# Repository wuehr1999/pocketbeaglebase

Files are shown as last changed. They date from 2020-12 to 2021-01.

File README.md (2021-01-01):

# pocketbeaglebase

Add lots of useful features to Your PocketBeagle.

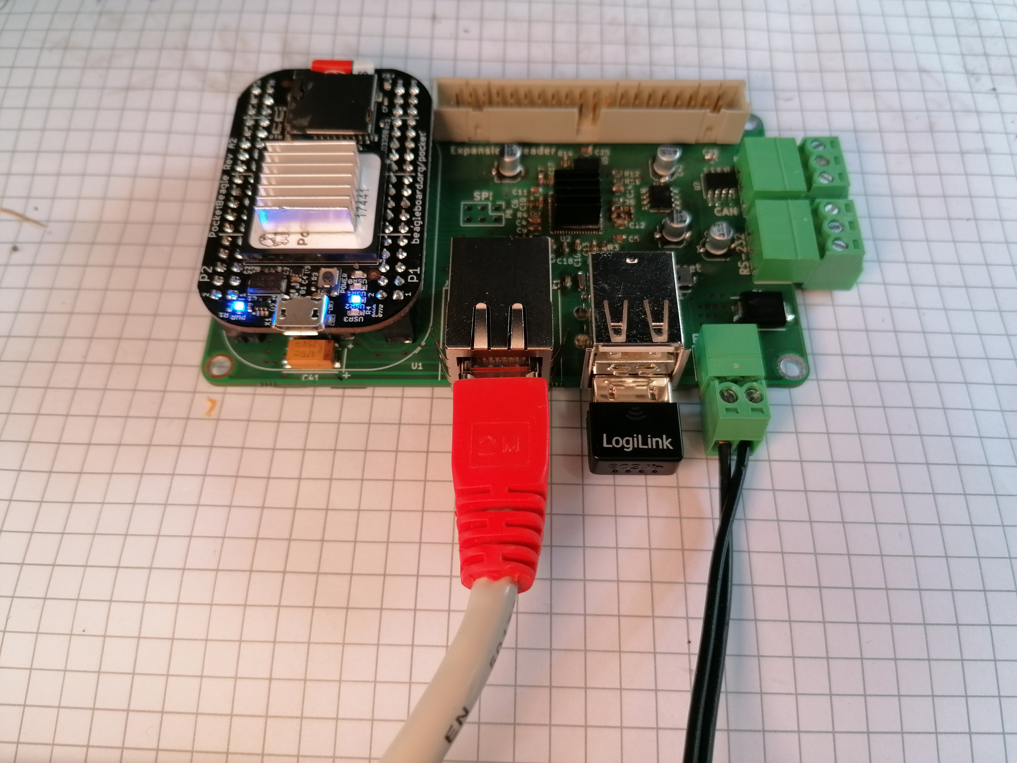
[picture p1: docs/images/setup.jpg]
pocketbeaglebase in use


## Features

* Input voltage range: 5 - 28V
* 10/100 Base-T/TX ethernet interface
* 2 USB 2.0 connectors
* RS-232 interface
* CAN interface
* Qwiic connectors: 2 x UART, PRU1 UART, ISC1
* SPI header
* GPIO header

## Connectors

### SPI1 header (P8)

| Pin | Function |
|-----|---|
| 1 | MISO |
| 2 | 3V3 |
| 3 | SCK |
| 4 | MOSI |
| 5 | CS |
| 6 | GND |

### GPIO header (P4)

| Pin | Function |
|-----|---|
| 1 | AIN7 |
| 2 | AIN5 |
| 3 | PRU0.5 |
| 4 | IO45 |
| 5 | PRU0.3 |
| 6 | PRU0.2 |
| 7 | IO48 |
| 8 | PRU0.6 |
| 9 | IO64 |
| 10 | IO46 |
| 11 | IO65 |
| 12 | IO27 |
| 13 | IO52 |
| 14 | IO47 |
| 15 | IO60 |
| 16 | IO57 |
| 17 | IO58 |
| 18 | IO23 |
| 19 | IO59 |
| 20 | PWM0A |
| 21 | PWM0B |
| 22 | 3V3 |
| 23 | PRU1.10 |
| 24 | IO26 |
| 25 | PRU0.1 |
| 26 | PRU0.4 |
| 27 | PRU0.7 |
| 28 | AIN4 |
| 29 | NC |
| 30 | AIN3 |
| 31 | NC |
| 32 | AIN2 |
| 33 | AIN1 |
| 34 | IO20 |
| 35 | AIN0 | 
| 36 | VRef+ |
| 37 | VRef- |
| 38 | IO89 |
| 39 | AIN6 |
| 40 | GND |

### RS-232 (UART 0)

| Pin | Function |
|-----|---|
| 1 | TX |
| 2 | RX |
| 3 | GND |

### CAN (CAN 0)

| Pin | Function |
|-----|---|
| 1 | CANH |
| 2 | CANL |
| 3 | GND |

The termination can be enabled by closing solder jumper P9 on the bottom of the board.

### UART2, UART4, UARTPRU1 over Qwiic (P3, P5, P6)

| Pin | Function |
|-----|---|
| 1 | GND |
| 2 | 3v3 |
| 3 | TX |
| 4 | RX |

### I2C1 over Qwiic (P7)

| Pin | Function |
|-----|---|
| 1 | GND |
| 2 | 3v3 |
| 3 | SDA |
| 4 | SCL |

## PCB

### Toplayer

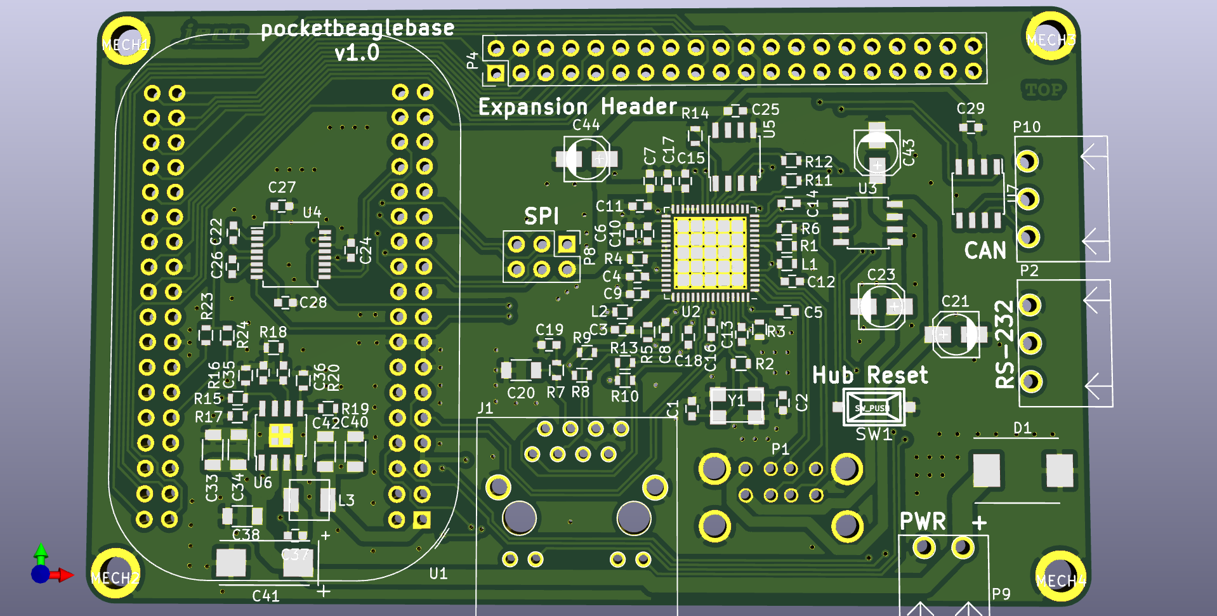
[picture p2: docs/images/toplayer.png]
toplayer


### Bottomlayer

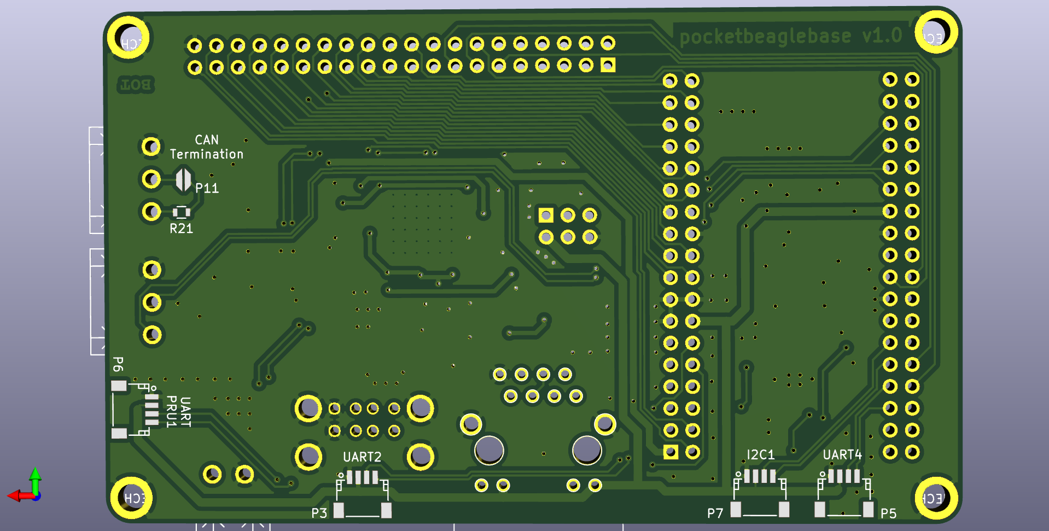
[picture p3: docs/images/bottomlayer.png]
bottomlayer


## Resources

### Manuals

* PocketBeagle System Reference Manual: https://github.com/beagleboard/pocketbeagle/wiki/System-Reference-Manual
* BeagleBone PRU Cookbook: http://beagleboard.org/static/prucookbook/

### Datasheets

* http://ww1.microchip.com/downloads/en/devicedoc/00002306a.pdf
* https://octavosystems.com/docs/osd335x-sm-datasheet/
* https://www.ti.com/lit/ds/symlink/sn65hvd230.pdf?HQS=dis-dk-null-digikeymode-dsf-pf-null-wwe&ts=1609524456800
* https://datasheets.maximintegrated.com/en/ds/MAX3224-MAX3245.pdf
* https://www.ti.com/lit/ds/symlink/tps54335-2a.pdf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
* http://ww1.microchip.com/downloads/en/devicedoc/21712b.pdf
* https://cdn-reichelt.de/documents/datenblatt/C100/M100_T1D_33E4G_DB_DE.pdf

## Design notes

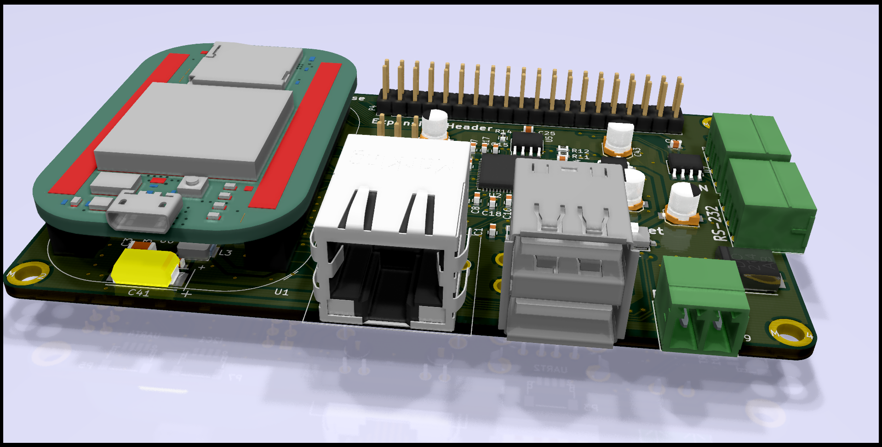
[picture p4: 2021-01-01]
docs/images/rendering.png

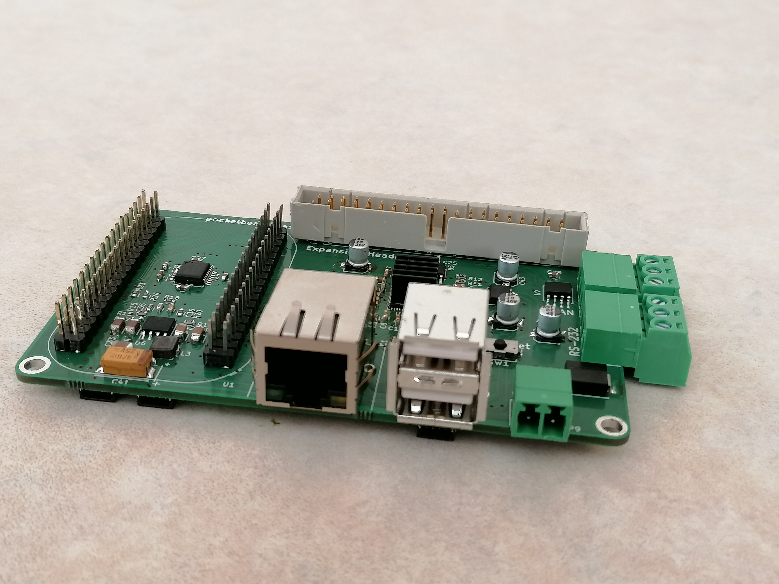
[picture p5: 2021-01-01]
docs/images/topside.jpg

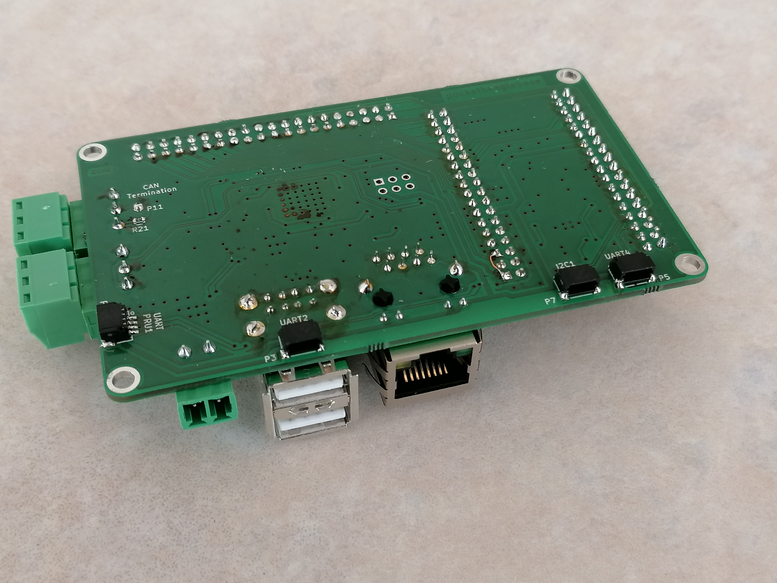
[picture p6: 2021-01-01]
docs/images/bottomside.jpg

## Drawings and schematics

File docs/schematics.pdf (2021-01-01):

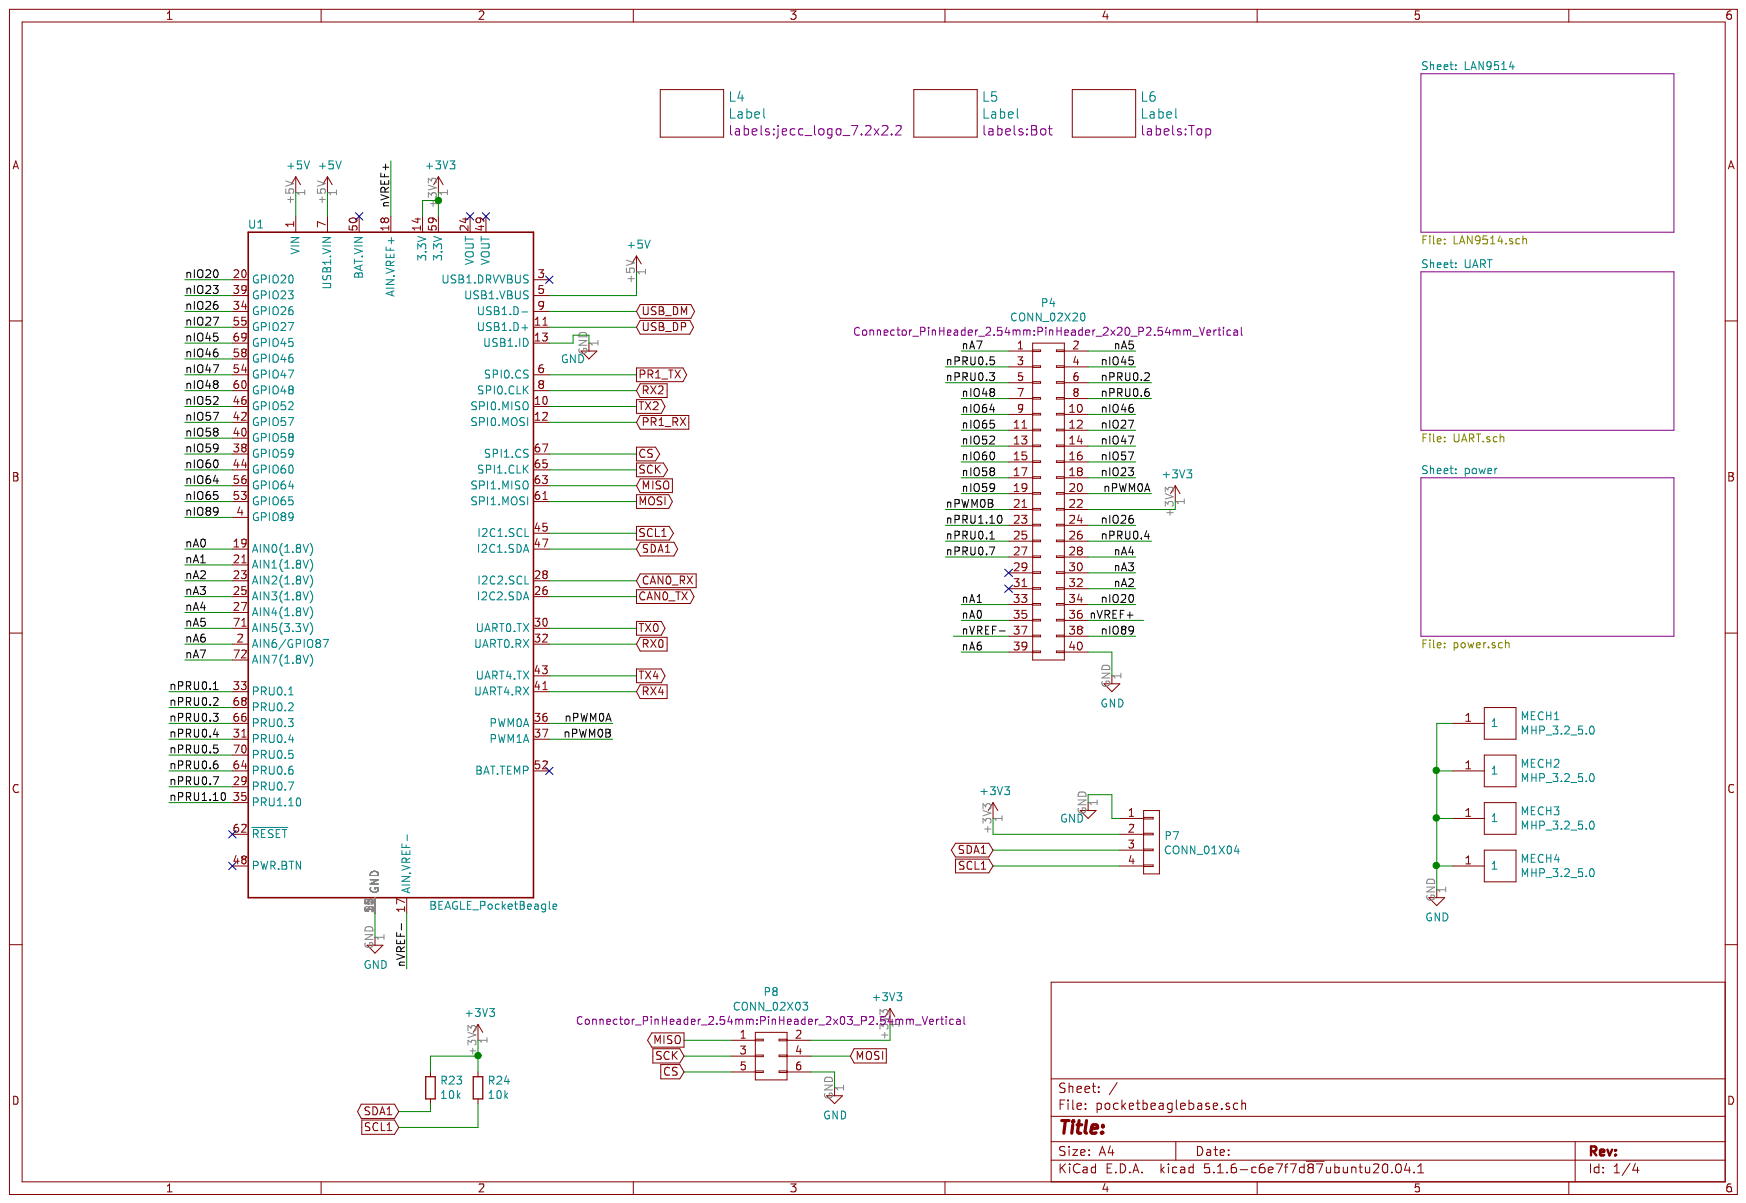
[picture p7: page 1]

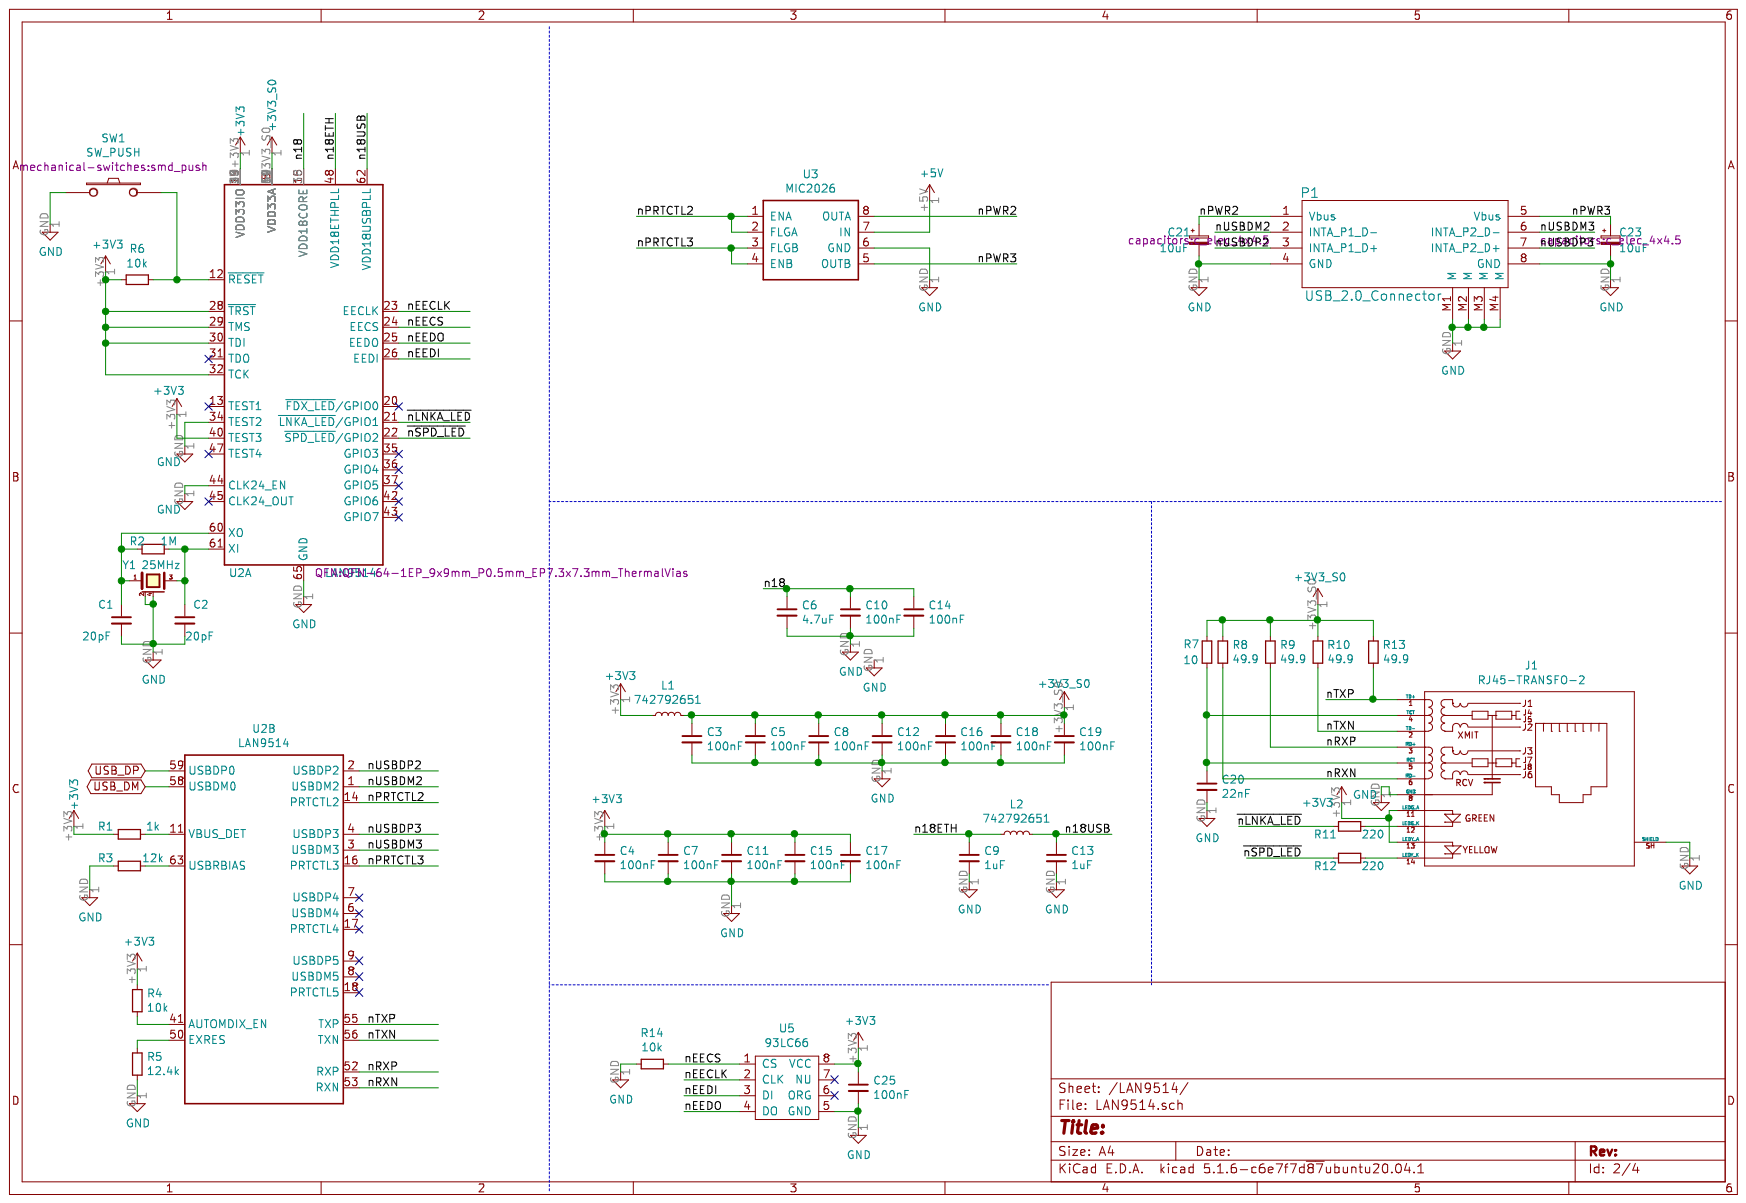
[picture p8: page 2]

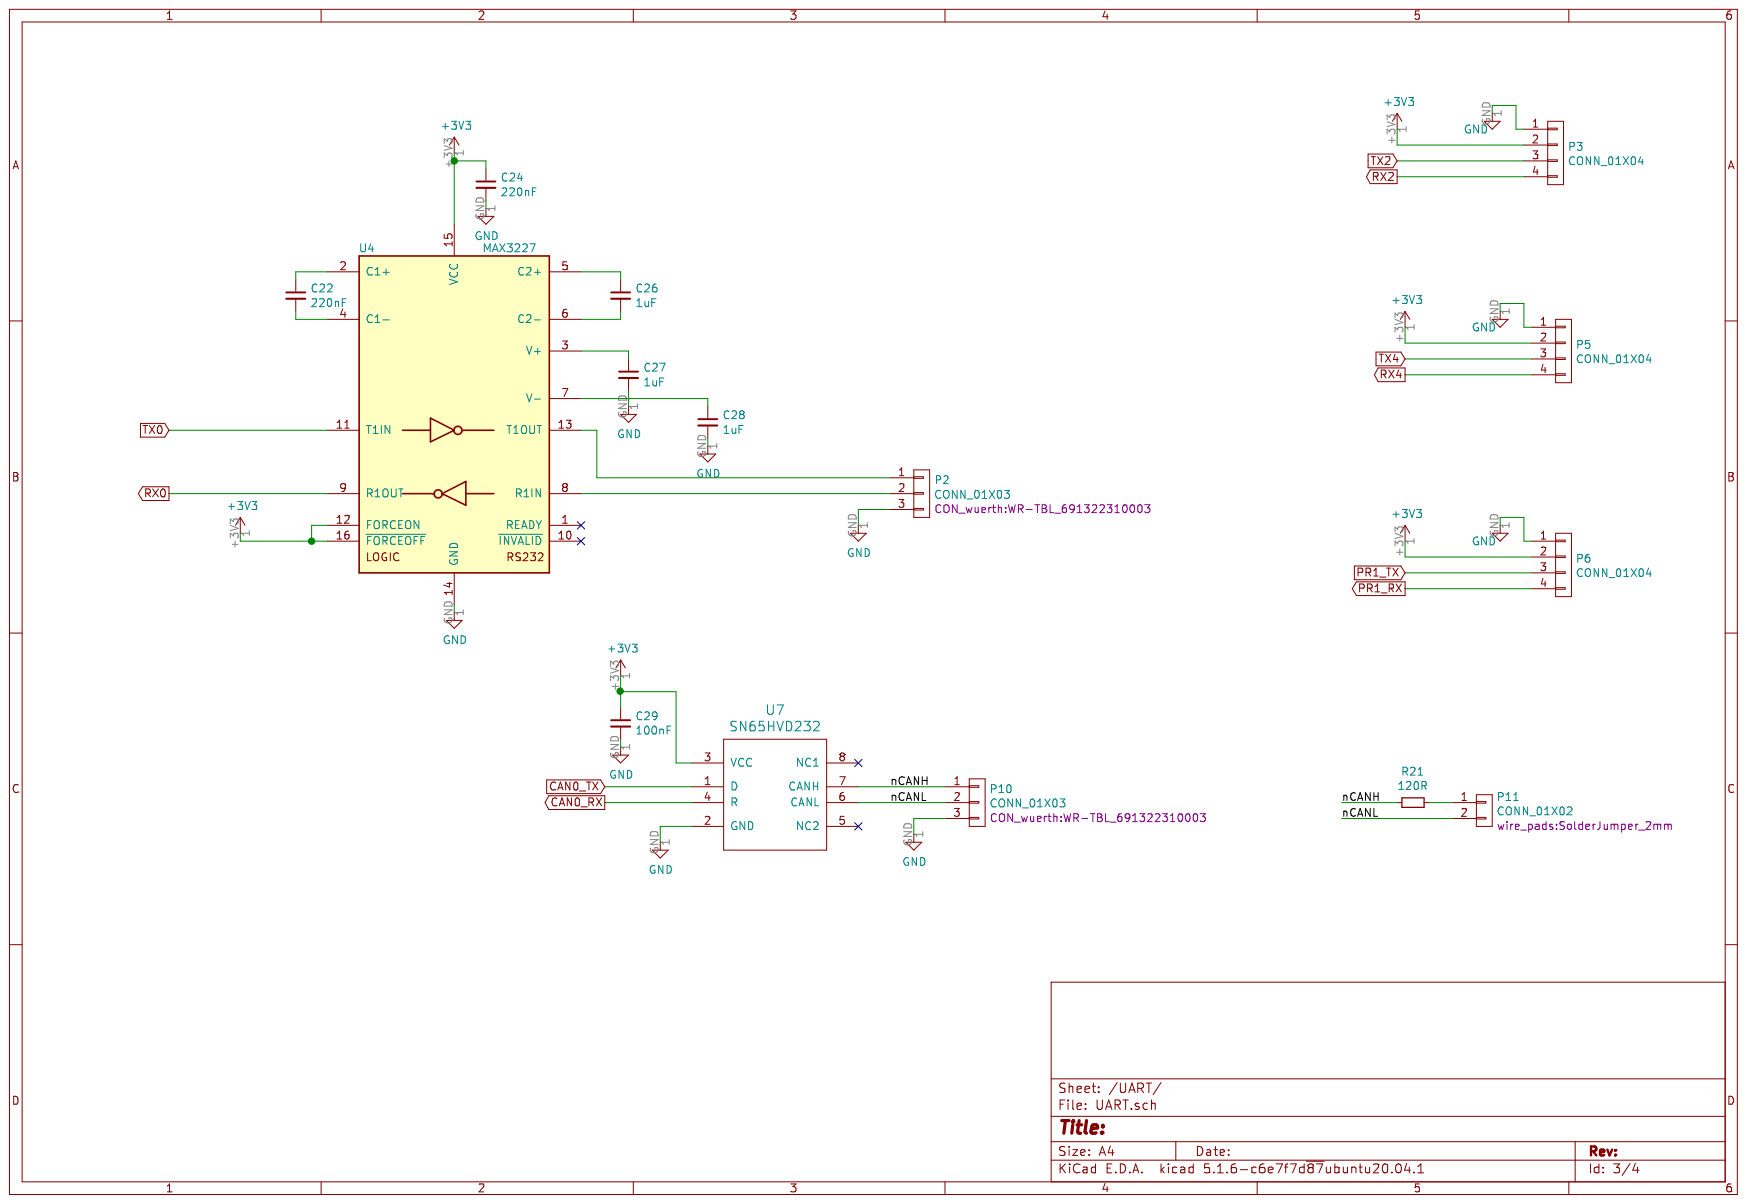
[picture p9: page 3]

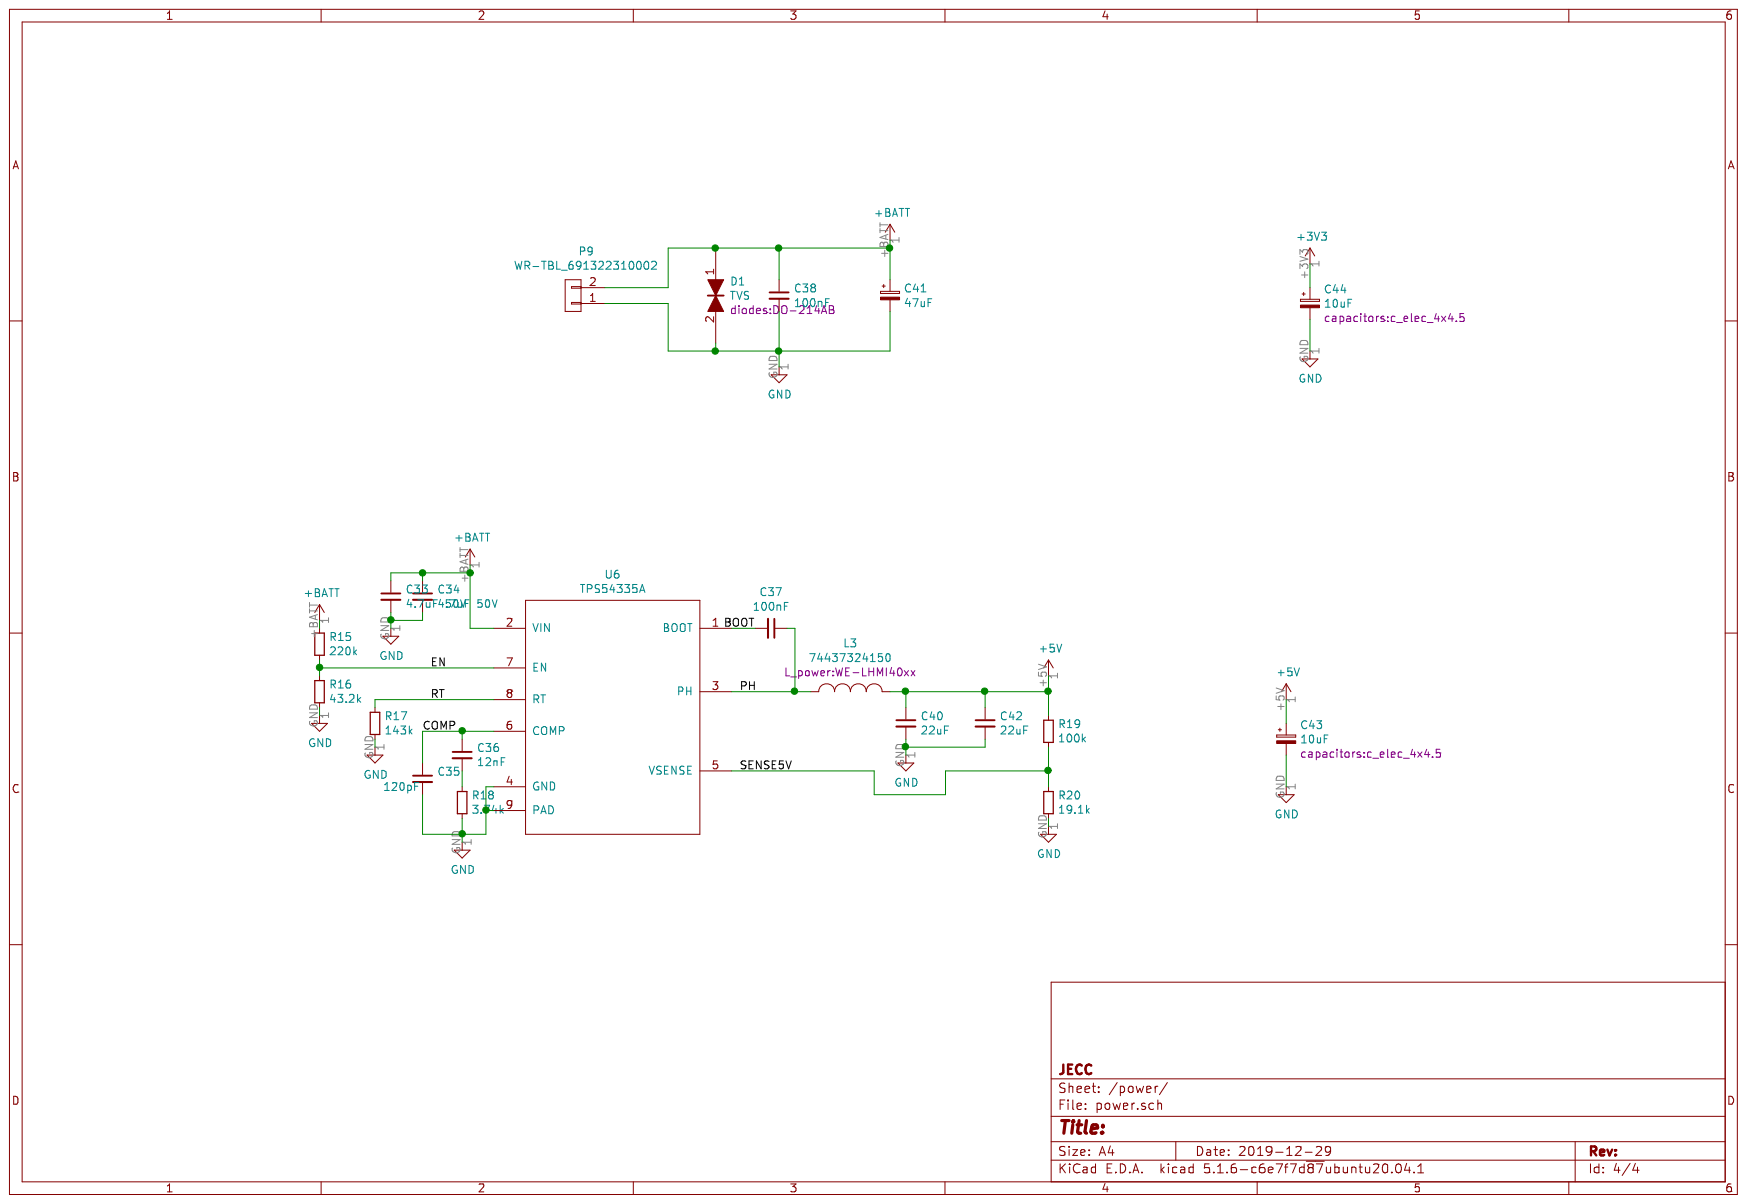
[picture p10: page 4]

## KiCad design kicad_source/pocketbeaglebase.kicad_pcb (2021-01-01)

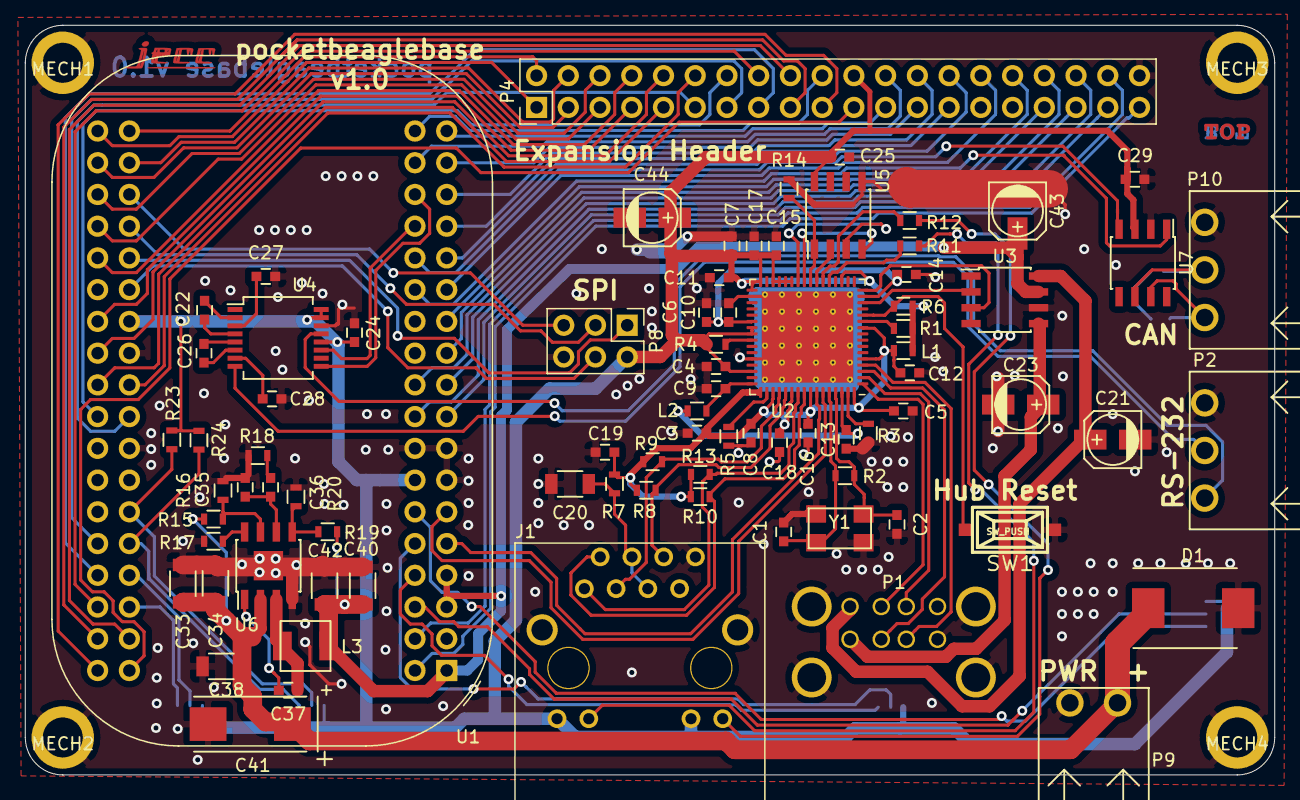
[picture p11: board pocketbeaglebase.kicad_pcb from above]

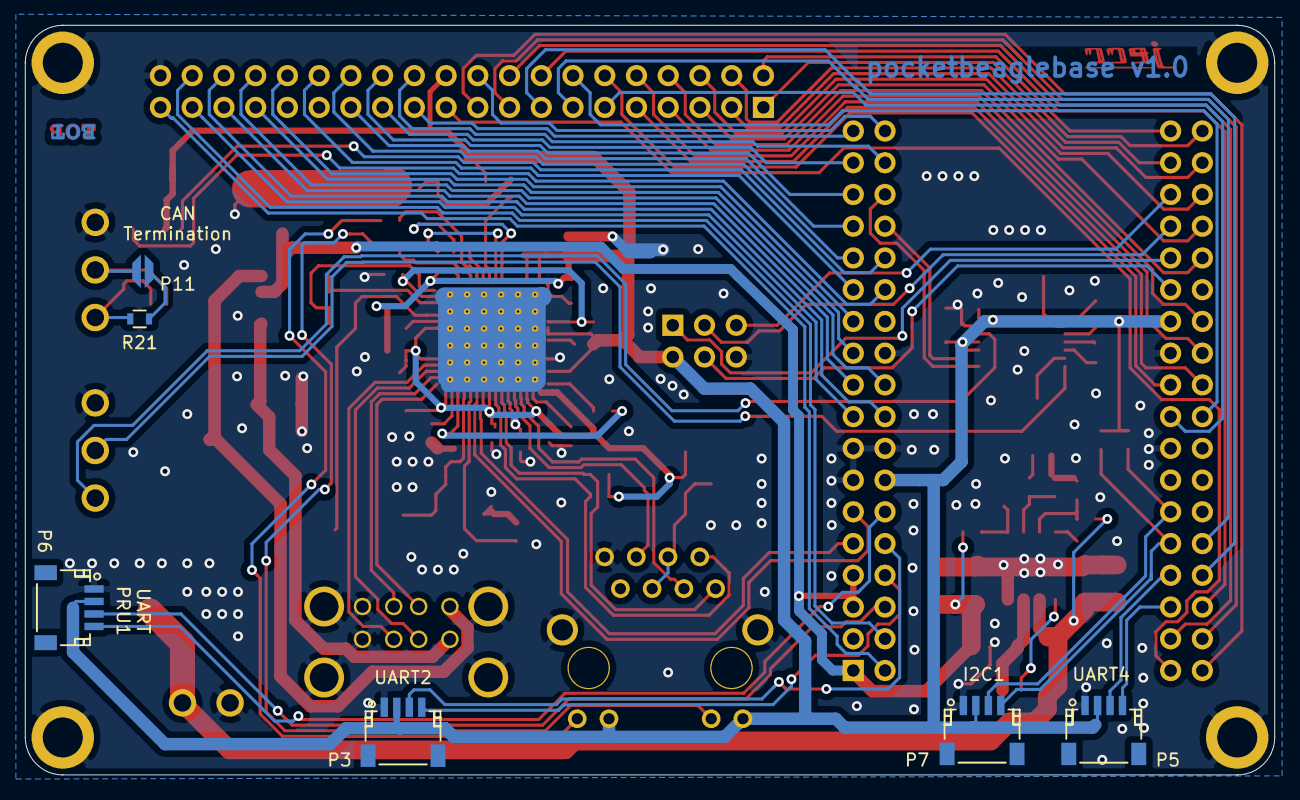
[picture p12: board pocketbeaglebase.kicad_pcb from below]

Board: 2 copper layers, 100.0 x 60.0 mm, 95 parts (6 on the bottom side), 108 nets.

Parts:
C1, C2: 330pF; C_0603
C3, C4, C5, C7, C8, C10, C11, C12, C14, C15, C16, C17, C18, C19, C25, C29, C37: 100nF; C_0603
C6: 4.7uF; C_0603
C9, C13, C26, C27, C28: 1uF; C_0603
C20: 22nF; C_1206
C21, C23, C43, C44: 10uF; c_elec_4x4.5
C22, C24: 220nF; C_0603
C33, C34: 4.7uF 50V; C_1206
C35: 120pF; C_0603
C36: 12nF; C_0603
C38: 100nF; C_1206
C40, C42: 22uF; C_1206
C41: 47uF; TantalC_SizeD_EIA-7343_Wave
D1: TVS; DO-214AB
J1: RJ45-TRANSFO-2; RJ_45_TRANSFO_2
L1, L2: 742792651; R_0603
L3: 74437324150; WE-LHMI40xx
L4: Label; jecc_logo_7.2x2.2
L5: Label; Bot
L6: Label; Top
MECH1, MECH2, MECH3, MECH4: MHP_3.2_5.0
P1: USB_2.0_Connector; WE-61400826021
P2, P10: CONN_01X03; WR-TBL_691322310003
P3, P5, P6, P7: CONN_01X04; Connectors_JST_SM04B-SRSS-TB
P4: CONN_02X20; PinHeader_2x20_P2.54mm_Vertical
P8: CONN_02X03; PinHeader_2x03_P2.54mm_Vertical
P9: WR-TBL_691322310002
P11: CONN_01X02; SolderJumper_2mm
R1: 1k; R_0603
R2: 1M; R_0603
R3: 12k; R_0603
R4, R6, R14, R23, R24: 10k; R_0603
R5: 12.4k; R_0603
R7: 10; R_0603
R8, R9, R10, R13: 49.9; R_0603
R11, R12: 220; R_0603
R15: 220k; R_0603
R16: 43.2k; R_0603
R17: 143k; R_0603
R18: 3.74k; R_0603
R19: 100k; R_0603
R20: 19.1k; R_0603
R21: 120R; R_0603
SW1: SW_PUSH; smd_push
U1: BEAGLE_PocketBeagle
U2: LAN9514; QFN-64-1EP_9x9mm_P0.5mm_EP7.3x7.3mm_ThermalVias
U3: MIC2026; SOIC-8_3.9x4.9mm_Pitch1.27mm
U4: MAX3227; SSOP-16_5.3x6.2mm_Pitch0.65mm
U5: 93LC66; SOIC-8_3.9x4.9mm_Pitch1.27mm
U6: TPS54335A; SOIC-8-1EP_3.9x4.9mm_Pitch1.27mm
U7: SN65HVD232; SOIC-8_3.9x4.9mm_Pitch1.27mm
Y1: 25MHz; Crystal_SMD_5x3.2mm_4Pad

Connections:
+3V3: C4.1, C7.1, C11.1, C15.1, C17.1, C24.1, C25.1, C29.1, C44.1, J1.11, J1.13, L1.1, P3.2, P4.22, P5.2, P6.2, P7.2, P8.2, R1.2, R4.1, R6.2, R23.1, R24.1, U1.14, U1.59, U2.19, U2.27, U2.28, U2.29, U2.30, U2.32, U2.33, U2.39, U2.40, U2.46, U4.12, U4.15, U4.16, U5.8, U7.3
+3V3_S0: C3.1, C5.1, C8.1, C12.1, C16.1, C18.1, C19.1, L1.2, R7.1, R8.1, R9.1, R10.1, R13.1, U2.5, U2.10, U2.49, U2.51, U2.54, U2.57, U2.64
+5V: C40.1, C42.1, C43.1, L3.2, R19.1, U1.1, U1.5, U1.7, U3.7
+BATT: C33.1, C34.1, C38.1, C41.1, D1.1, P9.2, R15.1, U6.2
/LAN9514/n18: C6.1, C10.1, C14.1, U2.15, U2.38
/LAN9514/n18ETH: C9.1, L2.1, U2.48
/LAN9514/n18USB: C13.1, L2.2, U2.62
/LAN9514/nEECLK: U2.23, U5.2
/LAN9514/nEECS: R14.1, U2.24, U5.1
/LAN9514/nEEDI: U2.26, U5.3
/LAN9514/nEEDO: U2.25, U5.4
/LAN9514/nPRTCTL2: U2.14, U3.1, U3.2
/LAN9514/nPRTCTL3: U2.16, U3.3, U3.4
/LAN9514/nPWR2: C21.1, P1.1, U3.8
/LAN9514/nPWR3: C23.1, P1.5, U3.5
/LAN9514/nRXN: J1.6, R8.2, U2.53
/LAN9514/nRXP: J1.3, R9.2, U2.52
/LAN9514/nTXN: J1.2, R10.2, U2.56
/LAN9514/nTXP: J1.1, R13.2, U2.55
/LAN9514/nUSBDM2: P1.2, U2.1
/LAN9514/nUSBDM3: P1.6, U2.3
/LAN9514/nUSBDP2: P1.3, U2.2
/LAN9514/nUSBDP3: P1.7, U2.4
/LAN9514/~nLNKA_LED: R11.1, U2.21
/LAN9514/~nSPD_LED: R12.1, U2.22
/UART/nCANH: P10.1, R21.2, U7.7
/UART/nCANL: P10.2, P11.2, U7.6
/nA0: P4.35, U1.19
/nA1: P4.33, U1.21
/nA2: P4.32, U1.23
/nA3: P4.30, U1.25
/nA4: P4.28, U1.27
/nA5: P4.2, U1.71
/nA6: P4.39, U1.2
/nA7: P4.1, U1.72
/nIO20: P4.34, U1.20
/nIO23: P4.18, U1.39
/nIO26: P4.24, U1.34
/nIO27: P4.12, U1.55
/nIO45: P4.4, U1.69
/nIO46: P4.10, U1.58
/nIO47: P4.14, U1.54
/nIO48: P4.7, U1.60
/nIO52: P4.13, U1.46
/nIO57: P4.16, U1.42
/nIO58: P4.17, U1.40
/nIO59: P4.19, U1.38
/nIO60: P4.15, U1.44
/nIO64: P4.9, U1.56
/nIO65: P4.11, U1.53
/nIO89: P4.38, U1.4
/nPRU0.1: P4.25, U1.33
/nPRU0.2: P4.6, U1.68
/nPRU0.3: P4.5, U1.66
/nPRU0.4: P4.26, U1.31
/nPRU0.5: P4.3, U1.70
/nPRU0.6: P4.8, U1.64
/nPRU0.7: P4.27, U1.29
/nPRU1.10: P4.23, U1.35
/nPWM0A: P4.20, U1.36
/nPWM0B: P4.21, U1.37
/nVREF+: P4.36, U1.18
/nVREF-: P4.37, U1.17
/power/COMP: C35.1, C36.1, U6.6
/power/EN: R15.2, R16.1, U6.7
/power/PH: C37.1, L3.1, U6.3
/power/RT: R17.1, U6.8
/power/SENSE5V: R19.2, R20.1, U6.5
CAN0_RX: U1.28, U7.4
CAN0_TX: U1.26, U7.1
CS: P8.5, U1.67
GND: C1.2, C2.2, C3.2, C4.2, C5.2, C6.2, C7.2, C8.2, C9.2, C10.2, C11.2, C12.2, C13.2, C14.2, C15.2, C16.2, C17.2, C18.2, C19.2, C20.2, C21.2, C23.2, C24.2, C25.2, C27.2, C28.2, C29.2, C33.2, C34.2, C35.2, C38.2, C40.2, C41.2, C42.2, C43.2, C44.2, D1.2, J1.8, J1.SH, MECH1.1, MECH2.1, MECH3.1, MECH4.1, P1.4, P1.8, P1.M1, P1.M2, P1.M3, P1.M4, P2.3, P3.1, P4.40, P5.1, P6.1, P7.1, P8.6, P9.1, P10.3, R3.2, R5.2, R14.2, R16.2, R17.2, R18.2, R20.2, SW1.1, U1.13, U1.15, U1.16, U1.22, U1.51, U1.57, U2.34, U2.44, U2.65, U3.6, U4.14, U5.5, U6.4, U6.9, U7.2, Y1.2, Y1.4
MISO: P8.1, U1.63
MOSI: P8.4, U1.61
unnamed: C1.1, R2.2, U2.60, Y1.1
unnamed: C2.1, R2.1, U2.61, Y1.3
unnamed: C20.1, J1.4, J1.5, R7.2
unnamed: C22.1, U4.2
unnamed: C22.2, U4.4
unnamed: C26.1, U4.5
unnamed: C26.2, U4.6
unnamed: C27.1, U4.3
unnamed: C28.1, U4.7
unnamed: C36.2, R18.1
unnamed: C37.2, U6.1
unnamed: J1.12, R11.2
unnamed: J1.14, R12.2
unnamed: P2.1, U4.13
unnamed: P2.2, U4.8
unnamed: P11.1, R21.1
unnamed: R1.1, U2.11
unnamed: R3.1, U2.63
unnamed: R4.2, U2.41
unnamed: R5.1, U2.50
unnamed: R6.1, SW1.2, U2.12
PR1_RX: P6.4, U1.12
PR1_TX: P6.3, U1.6
RX0: U1.32, U4.9
RX2: P3.4, U1.8
RX4: P5.4, U1.41
SCK: P8.3, U1.65
SCL1: P7.4, R24.2, U1.45
SDA1: P7.3, R23.2, U1.47
TX0: U1.30, U4.11
TX2: P3.3, U1.10
TX4: P5.3, U1.43
USB_DM: U1.9, U2.58
USB_DP: U1.11, U2.59

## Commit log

2020-12-10 added current state
    [LAN9514.sch, UART.sch, pocketbeaglebase.kicad_pcb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]
2020-12-11 review and discussion done
    [LAN9514.sch, pocketbeaglebase.kicad_pcb]
2020-12-11 added can bus
    [LAN9514.sch, UART.sch, pocketbeaglebase.kicad_pcb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]
2020-12-12 somehow done with general layouting
    [pocketbeaglebase.kicad_pcb, power.sch]
2021-01-01 tested and fixed last bugs
    [LAN9514.sch, UART.sch, pocketbeaglebase.kicad_pcb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]
